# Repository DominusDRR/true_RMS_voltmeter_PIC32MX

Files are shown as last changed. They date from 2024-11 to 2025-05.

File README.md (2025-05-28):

# true_RMS_voltmeter_PIC32MX
AC voltmeter (true RMS) to measure 120VAC with a PIC32 microcontroller.

Project Description
This project features an alternating current (AC) voltmeter capable of measuring up to ±300V peak and a highly accurate frequency meter.

Key Features:
TRUE RMS Measurement: The device computes precise mathematical calculations on the analyzed signal to deliver an accurate true RMS value.
Frequency Meter: Accurately measures the frequency of the input AC signal, making it versatile for various applications.
Self-Powered Design: No external power source is required. The circuit is powered directly from the analyzed signal itself.

Texto alternativo (https://www.youtube.com/watch?v=dqBPHb_SDKo)

## [a. Project Concept.](ProjectConcept.md)
## [b. Signal conditioning circuit.](SignalConditioningCircuit.md)
## [c. Active filter design.](ActiveFilterDesign.md)
## [d. Assignment of microcontroller pins or terminals.](AssignmentMicrocontrollerPinsTerminals.md)
## [e. Simulation of the signal conditioning circuit.](SimulationSignalConditioningCircuit.md)
## [f. Signal conditioning testing with prototype hardware.](SignalConditioning.md)
## [g. PCB Layout.](PCBLayout.md)
## [h. RMS value calculation analysis.](RMSCalueCalculationAnalysis.md)  
## [i. Creating microcontroller code.](CreatingMicrocontrollerCode.md) 
## [j. Process of acquiring analog signal samples with the ADC.](ADC.md)
## [k. Task that controls the acoustic signal (buzzer).](Buzzer.md)
## [l. Task that manages the 7‐segment display.](Display.md)
## [m. Task that performs the RMS calculation.](RMS.md)
## [n. Task that manages the push button.](PushButton.md)

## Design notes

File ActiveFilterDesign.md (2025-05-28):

I have designed the second order filter with MCHP's FilterLab software, for a frequency of 1000 Hz.

Filter response

Filter response 2

I'm going to use 9.3k and 13k resistors respectively for R11 and R12, I don't think it will affect much for the designed frequency.

The idea of the filter is to eliminate any high frequency noise coming from the mains.

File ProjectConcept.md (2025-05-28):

I have a project in mind, which can be said to be more of a hobby than a professional one.

I need to measure the RMS voltage of the power grid, which must be 127VAC, however, that value varies on some occasions, so it is necessary to constantly visualize it.

A practical and effective solution would be to buy a voltmeter (digital or analogue) and that would be the whole challenge.

<p align="center">
  
</p>

However, since this is something I want to do for fun, I decided to build the voltmeter with elements I have, such as some microcontroller samples I acquired back in the day, but have never put them to practical use.

The first idea that occurred to me was to use a chip that is already a digital voltmeter. 

Digital voltmeter on a chip

This solution, I also think, would not be a big challenge. Obviously the PCB design and the placement of the elements would be something fun, but I prefer to write some code as well.

So I have decided to give it an additional plus. Apart from simply measuring and displaying the RMS voltage, I am going to add two more functionalities:

1. Using a push button, the hardware will stop displaying the voltage, and instead indicate the network frequency.

2. If the voltage is lower than a minimum value or higher than a maximum value, an acoustic signal will be activated to report said problem in the network.

Below I show a rather rough and incomplete block diagram of the hardware:

Block diagram

The first condition, which I chose, is that the maximum peak value of the AC voltage signal that the voltmeter could measure would be 300V (212.13 Vrms), this value is due to the fact that the microcontroller's ADC works with a maximum DC value of 3.0V, and in this way the calculations of the components could be in closed values (without many decimals).

So, when the voltage signal is 300V, at the ADC input it should be 3.0V, while when it is -300V, the voltage at the ADC input should be 0V.

This poses a system of 2 equations with two unknowns variables:

system of 2 equations with two unknown variables

When solving the equations, we have that the AC voltage signal must be given a gain (or rather, attenuated) and an offset added to it.

The gain (less than one, is 1/200) and the offset is 1.5V.

To attenuate the signal, as well as add the offset, I decided to use an operational amplifier in offset subtracter mode:

operational amplifier in offset subtracter mode

Where R1 and R2 would be 200k, Rf and Rx 1k and Vref 1.5V.

As I mentioned initially, I have several sample elements requested and left over from other projects, the operational amplifier I have is the MCP6L01, and I proceeded to perform a simulation with MPLAB Mindi to determine if this first part of the circuit works.

simulation with MPLAB Mindi

Something I remember right now is that the microcontroller works with 3.3V, but the ADC wants to work with a reference voltage of 3.0V, the reason is that using the same supply voltage is not exact, that is, it is close to 3.3V, but it usually varies slightly depending on various circumstances.

While having a fixed voltage reference, I think the ADC error would be smaller with respect to the LDO voltage.

Finally, the microcontroller I have is the PIC32MX170F256B.



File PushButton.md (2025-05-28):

The task that manages the pulsed pulses performs two actions, switching between the two operating modes, voltmeter and frequency meter; and eliminates the mechanical bounce.

The task has 3 states, the initial one, the one that eliminates the bounce and the last one that waits for the button to return to 1, if the user keeps it pressed.

<pre><code>typedef enum
{
    /* Application's state machine's initial state. */
    APPPULSADOR_ESTADO_INICIAL=0,
    APPPULSADOR_ESTADO_ELIMINAR_REBOTE,
    /* TODO: Define states used by the application state machine. */
    APPPULSADOR_ESTADO_ESPERAR_PULSADOR_REGRESE_A_1,
} APPPULSADOR_STATES;
</code></pre>

The data structure, apart from the state variable, has a flag that is used to determine the operating mode (voltmeter or frequency meter) and another 32-bit variable to be used to generate asynchronous delays.

<pre><code>typedef struct
{
    /* The application's current state */
    APPPULSADOR_STATES state;
    /* TODO: Define any additional data used by the application. */
    bool medirFrecuencia;
    int retardo;
} APPPULSADOR_DATA;
</code></pre>

In the initial state, the task is obviously initialized with the first state, and by default, the operation mode is voltmeter, that is, the medirFrecuencia flag is false.

<pre><code>void APPPULSADOR_Initialize ( void )
{
    /* Place the App state machine in its initial state. */
    apppulsadorData.state = APPPULSADOR_ESTADO_INICIAL;
    /* TODO: Initialize your application's state machine and other
     * parameters.
     */
    apppulsadorData.medirFrecuencia = false; // voltmeter mode
}</code></pre>

In the first state of the task, it waits for the button to be pressed and for the task that controls the buzzer to be at rest or in a higher state.

If so, medirFrecuencia switches state, that is, if it is true, it changes to false and vice versa, next the cambiarProceso function is called, which will change the operating states of the device, then the instantaneous value of the central timer is captured and the next state of the task is passed on.

<pre><code>case APPPULSADOR_ESTADO_INICIAL:
{
    if (false == PULSANTE_Get() && appbuzzerData.state >= APPBUZZER_ESTADO_REPOSO) // I wait for the button to be pressed
    {
        apppulsadorData.medirFrecuencia = !apppulsadorData.medirFrecuencia; //change the state of the boolean variable
        cambiarProceso();
        apppulsadorData.retardo = CORETIMER_CounterGet();
        apppulsadorData.state = APPPULSADOR_ESTADO_ELIMINAR_REBOTE;
     }
     break;
}</code></pre>

The cambiarProceso function restarts the tasks that perform ADC sampling and RMS calculation.

<pre><code>void cambiarProceso(void)
{
    APPSAMPLING_Initialize();   // Restart the sampling task
    APPRMS_Initialize();        // I restart the task that calculates the RMS value
}
</code></pre>

The debounce state waits for 200ms with an asynchronous delay before continuing.

The 200ms value is empirical, and it works very well for me.

After that delay, it is verified that the user has released the button to return to the initial state, otherwise, to the state where it waits for the user to stop pressing the button.

<pre><code> case APPPULSADOR_ESTADO_ELIMINAR_REBOTE:
{
   if ((CORETIMER_CounterGet() - apppulsadorData.retardo) > _200ms) 
   {
      if (false == PULSANTE_Get()) // the user continues to press the button
      {
         apppulsadorData.state = APPPULSADOR_ESTADO_ESPERAR_PULSADOR_REGRESE_A_1;
      }
      else
      {
         apppulsadorData.state = APPPULSADOR_ESTADO_INICIAL; // returns to wait for another keystroke
      }
    }
    break;
 }</code></pre>

In the state that waits for the user to release the button, that is, it is set to true.

Once the user releases the button, the state that eliminates the mechanical bounce is returned to.

<pre><code>
case APPPULSADOR_ESTADO_ESPERAR_PULSADOR_REGRESE_A_1:
{
    if (PULSANTE_Get()) // wait until the pulse returns to logic 1
    {
       apppulsadorData.retardo = CORETIMER_CounterGet();
       apppulsadorData.state = APPPULSADOR_ESTADO_ELIMINAR_REBOTE;
    }
    break;
}
/* The default state should never be executed. */
default: break; /* TODO: Handle error in application's state machine. */</code></pre>

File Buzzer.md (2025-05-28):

I have decided to use the buzzer to make a tune or music when the device is powered.

I have worked with the output comparator module before, doing exactly what I have described, and it works with a 16 or 32 bit timer to perform the comparison:

<p align="center">

</p>

In the MCC graphic area, I made a new group called buzzer:

<p align="center">

</p>

Inside which I have placed the OCMP1 module, which corresponds to the OC1 output:

<p align="center">

</p>

The features of the buzzer are as follows:

<p align="center">

</p>

There are several examples on the Internet of how to generate music with a PWM signal

The frequency of musical notes is in the approximate range from 200 Hz to 3000 Hz.

Therefore, to modify the PWM frequency, it is necessary to modify the PRy register of the associated timer:

<p align="center">

</p>

So, the value to compare is not important, but as a clock source, I select timer 3, so as not to interfere with the one that will be used with the square signal capture module synchronized with the sine wave:

<p align="center">

</p>

And I create a task with the name appBuzzer that will be dedicated to generating the initial music and warning tones:

<p align="center">

</p>

I have a project with a PIC32MZ microcontroller, with these definitions for each musical note, where each of them has the necessary frequency as a comment. For example, the musical note c_ corresponds to 261Hz, and the value to load in the PRy is 191570 to generate that frequency.

Obviously, for this microcontroller, which works at another frequency, I must recalculate those values.

<pre><code>#define mute 0
#define c_      191570 //       261 Hz underscore _ was used because there were conflicts with aws definitions or with freertos
#define d_      170067 //       294
#define e_      151974 //       329
#define f       143265 //       349
#define g       127876 //       391
#define gS      120481 //       415
#define a       113635 //       440
#define aS      112359 //       445
#define b       107295 //       466
#define cH      95601  //       523
#define cSH     90252  //       554
#define dH      85178  //       587
#define dSH     80385  //       622
#define eH      75872  //       659
#define fH      71632  //       698
#define fSH     67567  //       740
#define gH      63775  //       784
#define gSH     60240  //       830
#define aH      56817  //       880
                
#define cHH     23888   //      2093
#define AB      26823   //      1864
#define F6      35816   //      1396
#define d7      21285   //      2349
#define DE      20087   //      2489
#define f7      17901   //      2793
#define FG      16890   //      2960
#define GA      15050   //      3322
#define ABx     13407   //      3729
#define CD      22551   //      2217
#define E7      18960   //      2637
#define g7      15943   //      3136</code></pre>

According to the above definitions, the minimum frequency is 261 Hz and the maximum is 3136 Hz, this would imply a maximum period of the PWM signal of 3.831 ms and a minimum of 318.88 microseconds respectively.

Therefore, the PWM period should be greater than those 3.8 ms, for example the period could be 7 ms.

Playing with the parameters of timer 3, with a scaling of 8, that is, with 6 Mhz, and with PR3 equal to 42000, you would get 7 ms.

(42000/6MHz = 7 ms)

<p align="center">

</p>

Now, if we want a period of 318.88 us, PR3 = f* T = 6MHz * 318.88 us = 1913.26, which is a value that PR3 can have.

The equation to calculate the period of the PWM signal is:

<p align="center">

</p>

Where TPB is the clock frequency period of the peripheral bus, i.e. 1/48MHz.

TMR Prescaler Value is the pre-scaling value which is 8, i.e. TPB * TMR Prescaler Value = 1/6MHz.

With this I made a table in Excel to get the PR2 values for each audio frequency:

<p align="center">

</p>

And I paste it into the header file of the appbuzzer task: (obviously without decimals)

<p align="center">

</p>

A song is defined as a series of musical notes, and each note has a duration.

So I create a data structure as follows:

<pre><code>typedef struct
{
    unsigned int FrecuenciaNota; //frequency of the musical note
    unsigned int Tiempo;         //Time that a musical note lasts
}NotasMusicales;</code></pre>

Where NoteFrequency is the value of the timer's PR, and Time is the duration of the musical note, so I create an array with 12 musical notes like this:

<pre><code>NotasMusicales      Musica[0x0C];</code></pre>

I create this in the C file of the buzzer task.

<p align="center">

</p>

In the initial state of the task, what I do is initialize the 'music' array with the PR3 and delay values to generate the initial music.

<p align="center">

</p>

Remember that 1 ms is given by:

<pre><code>#define _1ms 0x5DC0</code></pre>

Also, in the initial state of the task (which I renamed) I disable everything related to the PWM configuration, otherwise it is possible that the buzzer makes sounds before the task starts to execute, and I start timer 3:

<p align="center">

</p>

I need a pointer to obtain each value of the array called Music, which will be part of the task data structure:

<p align="center">

</p>

And I initialize it in the C code of the task:

<p align="center">

</p>

Also, I need a variable to generate asynchronous (non-blocking) delays, and I write it in the data structure:

<p align="center">

</p>

To change the value of PR3, I create a function like this:

<pre><code>void actualizarFrecuenciaPWM(unsigned int frecuencia)
{
    TMR3_PeriodSet(frecuencia); //is similar to, PR3 = frecuencia (frequency);
    OCMP1_CompareSecondaryValueSet(frecuencia >> 1); // pulse width at 50%
}</code></pre>

Where I also try to make the PWM duty ratio % when writing to the OC1RS register, half the value of PR3.

At task initialization, I capture a value from the Core Timer, and generate the first note with the PWM using the actualizarFrecuenciaPWM function.

<p align="center">

</p>

In the initial state, I wait for the duration of each note using an asynchronous delay like this:

<p align="center">

</p>

When the delay has finished, the following is done:

A new core timer value is captured for the next delay.

I increment the pointer of the array called Music by 1.

If the pointer is still within the size of the music array, I check if the next note is mute, if so, I turn off the PWM to generate a silence.

If it is not mute, I update the value of PR3 with the value of the next note.

If the pointer is larger than the size of the array, the melody has finished, I turn off the PWM and jump to a state called sleep, where the task will wait until it wants to generate an acoustic signal.

That acoustic signal will be generated in a new state, but that will be later, for now I just want to create this part of the code.

Download the new code to the hardware and this is the result

<p align="center">

</p>

You can see that there is an unwanted tone before the melody starts.

I was assuming that some code is executed before initializing the task where I disable the PWM, I tried several things, for example setting the value to compare to 1 so that the initial pulse width is small, so that it does not generate that noise, like this:

<p align="center">

</p>

I also tried with a value equal to zero, but the result was the same.

I looked for where the PWM is initialized or activated, thinking that the generated code activated it ahead of time, but that is not the case. Where the PWM is activated is where I wrote OCMP1_Enable.

<p align="center">

</p>

So I came up with the idea of writing a note of silence, in the initial code, this implies that the Musica array is now 13 elements:

<p align="center">

</p>

By doing this, the melody sounded as it should.

"Test 2":https://www.youtube.com/watch?v=JiKf7lXYXPU

This task also activates an acoustic signal to inform if there is an overvoltage or an undervoltage, the levels for these levels are as follows:

<pre><code>#define maximoVoltaje       127.00
#define minimoVoltaje       110.00 
#define maximaFrecuencia    60.50
#define minimaFrecuencia    59.50</code></pre>

For an over-voltage, I want to make three audio pulses of 100 ms duration. Between each pulse there will be 200 ms, and before generating the three pulses again, I expect about 700 ms, something similar to this image which is not to scale.

<p align="center">

</p>

For an undervoltage, I think it will be a 100ms pulse, and between the next one, it will be about 700ms.

<p align="center">

</p>

I have created three more states, one that waits for the high tone, another that waits for the low tone and the third that waits for 700 ms to repeat the process again:

<pre><code>typedef enum
{
    /* Application's state machine's initial state. */
    APPBUZZER_ESTADO_INICIAL=0,
    APPBUZZER_ESTADO_REPOSO,
    /* TODO: Define states used by the application state machine. */
    APPBUZZER_ESTADO_PULSO_EN_ALTO,
    APPBUZZER_ESTADO_PULSO_EN_BAJO,
    APPBUZZER_ESTADO_PULSO_EN_SILENCIO
} APPBUZZER_STATES;</code></pre>

The task must be forced to change to the APPBUZZER_STATE_PULSE_ON_HIGH state, previously, the buzzer must be activated and the instantaneous value of the Core Timer must be captured to generate a 100ms delay.

This state would be like this:

<pre><code> case APPBUZZER_ESTADO_PULSO_EN_ALTO:
{
  if ((CORETIMER_CounterGet() - appbuzzerData.retardo) > _100ms)
  {
    OCMP1_Disable();
    appbuzzerData.retardo = CORETIMER_CounterGet();
    appbuzzerData.state = APPBUZZER_ESTADO_PULSO_EN_BAJO;
  }
  break;
}</code></pre>

Once the 100ms have elapsed, the buzzer is deactivated, an instantaneous value is captured again from the central timer for the next delay and the task status is changed to APPBUZZER_PULSE_STATE_IN_LOW.

The task data structure must have 3 additional data, an unsigned integer variable to capture the instantaneous value of the central timer, a variable where the number of desired audio pulses to be generated is written, and another that counts them,

<pre><code>typedef struct
{
    /* The application's current state */
    APPBUZZER_STATES state;
    /* TODO: Define any additional data used by the application. */
    unsigned char PunteroMusica;
    unsigned int retardo;
    unsigned char numeroPulsos; // number of pulses.
    unsigned char contadorPulsos; //pulse counter
} APPBUZZER_DATA;</code></pre>

The APPBUZZER_STATE_PULSE_IN_LOW state will be as follows, where 200ms is expected:

<pre><code>case APPBUZZER_ESTADO_PULSO_EN_BAJO:
{
     if ((CORETIMER_CounterGet() - appbuzzerData.retardo) > _200ms)
     {
         appbuzzerData.contadorPulsos--;
         if (appbuzzerData.contadorPulsos)
         {
             OCMP1_Enable();
             appbuzzerData.state = APPBUZZER_ESTADO_PULSO_EN_ALTO;
         }
         else
         {
             appbuzzerData.state = APPBUZZER_ESTADO_PULSO_EN_SILENCIO;
         }
         appbuzzerData.retardo = CORETIMER_CounterGet();
    }
    break;
</code></pre>

When 200 ms have passed, the variable pulse_counter is decremented. If it is still greater than zero (if (appbuzzerData. pulse_counter)), the buzzer is activated again and the task changes back to the APPBUZZER_PULSE_STATE_ON_HIGH state.

If it is zero (else), the task changes back to the APPBUZZER_PULSE_STATE_ON_SILENCE state.

This case does not end without first capturing the value that the Core Timer has at that moment.

In the APPBUZZER_PULSE_STATE_ON_SILENCE state, 500 ms are expected, which added to the previous 200, would give 700 ms.

<pre><code>case APPBUZZER_ESTADO_PULSO_EN_SILENCIO:
 {
     if ((CORETIMER_CounterGet() - appbuzzerData.retardo) > _500ms)
     {
           appbuzzerData.contadorPulsos = appbuzzerData.numeroPulsos;
           appbuzzerData.retardo = CORETIMER_CounterGet();
           OCMP1_Enable();
           appbuzzerData.state = APPBUZZER_ESTADO_PULSO_EN_ALTO;
     }
     break;
}</code></pre>

After the delay, the value of the variable pulse_counter is restored using pulse_number, the value of the Core Timer is captured again, the buzzer is activated and the state APPBUZZER_PULSE_STATE_ON_HIGH is returned to.

The function that changes the buzzer task's sleep time would be as follows:

<pre><code>void analizarNivelVoltaje(float voltajeRMS)
{
    if (appbuzzerData.state > APPBUZZER_ESTADO_INICIAL)
    {
        float valorMaximo;
        float valorMinimo;
        if (apppulsadorData.medirFrecuencia)
        {
            valorMaximo = maximaFrecuencia;
            valorMinimo = minimaFrecuencia;
        }
        else
        {
            valorMaximo = maximoVoltaje;
            valorMinimo = minimoVoltaje;
        }
        if (voltajeRMS > valorMaximo)
        {
            if (0x03 == appbuzzerData.numeroPulsos) // Overvoltage alarm is now present
            {
                return;
            }
            appbuzzerData.numeroPulsos = 0x03;
        }
        else if (voltajeRMS < valorMinimo)
        {
            if (0x01 == appbuzzerData.numeroPulsos) // Undervoltage alarm is now present
            {
                return;
            }
            appbuzzerData.numeroPulsos = 0x01;
        }
        else
        {
            appbuzzerData.numeroPulsos = 0x00;
            OCMP1_Disable();//apago el PWM
            appbuzzerData.state = APPBUZZER_ESTADO_REPOSO;
            return;
        }
        appbuzzerData.contadorPulsos = appbuzzerData.numeroPulsos;
        appbuzzerData.retardo = CORETIMER_CounterGet();
        actualizarFrecuenciaPWM(cHH);
        OCMP1_Enable();
        appbuzzerData.state = APPBUZZER_ESTADO_PULSO_EN_ALTO;
    }
}</code></pre>

This function should be called when the RMS value is calculated, and I have put it when the value on the displays is going to be modified:

<p align="center">

</p>

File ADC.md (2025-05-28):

The first basic conceptual idea is that the square signal that would be generated synchronized with the 60Hz network would be useful to start and stop the acquisition of data or samples from the ADC.

The start and stop would be by the rising or positive edge of said signal, as follows:

<p align="center">

</p>

The problem is that I don't know how many machine cycles it takes to calculate the RMS value (it could be measured), as you can see in the image above, once the data acquisition is finished, the CPU would concentrate on performing that calculation.

I don't think it would take a long time, but nevertheless, it would have to wait for the next cycle of the sinusoidal signal to perform a new data acquisition, I don't think it would affect the accuracy of the calculation, but I don't like the idea of wasting time doing that process.

The second option is to always be acquiring the data from the ADC.

This would imply using two buffers or arrays to store the information.

In the first cycle, it would save in the first array, then the task that calculates the RMS would perform its calculations with that array, but in that same cycle, the ADC information would be saved in the second array.

Then at the end of the second cycle, the RMS would be calculated with the second array, and the information would be stored in the first one, something like this image:

<p align="center">

</p>

So far, the idea that information is always being acquired from the sinusoidal signal seems to work, however, it is possible that the RMS calculation operations are atomic instructions, that is, they cannot be divided into more subfunctions, and executing them takes some time, so that, for example, if you are waiting for the data acquisition time, that time is longer, because some part of the RMS calculation is not finished.

The acquisition time is 1 us, the conversion time is approximately 14 us, and between each sample, you must wait 100 us:

<p align="center">

</p>

I was thinking about using polled mode, meaning I wait for a flag to finish, to know if the ADC conversion is ready. But as I mentioned, the CPU could be running an RMS calculation process, and until it finishes and checks that ADC flag again, the time will be longer, and possibly generate some precision error.

Also, I use asynchronous delays, which are not precise, and are used for tasks that are not so critical, for example, in the displays, each one shows information at a rate of 1000 us (1ms), but if for some moment it were 1015 us, for example, the user will not notice that.

Regarding the operation of the microcontroller's ADC.

The ADC has a 16-word buffer that I thought would be useful for acquiring 16 samples automatically.

<p align="center">

</p>

Now, the signal you want to sample with the ADC is approximately 60 Hz or a period of 16.667 ms.

The sampling must be much less than that time, for example if it were 100 times smaller, it would be 166.667 us, so you could choose a sampling rate of 100 us or 10 ksps.

Here you have to consider the acquisition time and the conversion time.

<p align="center">

</p>

According to the ADC converter section manual, the signal acquisition time is given by the ADCS bits of the ADCON3 register

<p align="center">

</p>

The minimum time must be greater than 83.33 ns.

<p align="center">

</p>

And in my case TpB is 1/48MHz.

<p align="center">

</p>

Looking for a correct value for the ADCS bits, I can say that 1 us acquisition time can be achieved:

<p align="center">

</p>

According to the manual, the conversion time is 12 times TAD, plus 1 or 2 additional TADs, therefore the conversion time would be approximately 14 us

<p align="center">

</p>

That is, the sampling would be at a rate of 15 us or 66.67 ksps.

This would allow for more samples, i.e. a more precise calculation, or perhaps use a delay to wait for the 100 us.

So I am forced to use interrupts, both, for the completion of the ADC conversion and for the generation of 100 us.

In that way, I think the latency produced by the RMS calculation process would be improved.

For the ADC converter interrupt, I take the MHCP example called adc_interrupt_pic32mx470_curiosity

And the example is as follows:

<pre><code>void ADC_ResultHandler(uintptr_t context)
{
    /* Read the ADC result */
    adc_count = ADC_ResultGet(ADC_RESULT_BUFFER_0);
    result_ready = true;
}

int main ( void )
{
    /* Initialize all modules */
    SYS_Initialize ( NULL );
    ADC_CallbackRegister(ADC_ResultHandler, (uintptr_t)NULL);
 
    printf("\n\r---------------------------------------------------------");
    printf("\n\r                    ADC Demo                 ");
    printf("\n\r---------------------------------------------------------\n\r");
 
    /* Start ADC conversion */
    ADC_ConversionStart();

    while (1)
    {
        /* Maintain state machines of all polled MPLAB Harmony modules. */
        SYS_Tasks ( );
 
        /* Auto sampling mode is used, so no code is needed to start sampling */
 
        /* Wait till ADC conversion result is available */
        if(result_ready == true)
        {
            result_ready = false;
            input_voltage = (float)adc_count * ADC_VREF / ADC_MAX_COUNT;
            printf("ADC Count = 0x%03x, ADC Input Voltage = %d.%02d V \r", adc_count, (int)input_voltage, (int)((input_voltage - (int)input_voltage)*100.0));
 
            /* Start ADC conversion */
            ADC_ConversionStart();
        }
    }
 
    /* Execution should not come here during normal operation */
 
    return ( EXIT_FAILURE );
}</code></pre>

It can be assigned or registered with the ADC_CallbackRegister function, which is the function that will handle the interruption at the end of the ADC conversion.

This function is called ADC_ResultHandler, where it obtains the value of the conversion and saves it in the variable adc_count

The configuration of this peripheral, with the graphic area of the MCC is as shown:

<p align="center">

</p>

Regarding the interruption by a timer, the example that I am going to take as a reference is called tmr_timer_mode_pic32mx_12_sk

<pre><code>/* This function is called after period matches in Timer 3 (32-bit timer) */
void TIMER2_InterruptSvcRoutine(uint32_t status, uintptr_t context)
{
    /* Toggle LED */
    LED1_Toggle();
}
// *****************************************************************************
// *****************************************************************************
// Section: Main Entry Point
// *****************************************************************************
// *****************************************************************************
 
int main ( void )
{
    /* Initialize all modules */
    SYS_Initialize ( NULL );
    
    TMR2_CallbackRegister(TIMER2_InterruptSvcRoutine, (uintptr_t) NULL);
    TMR2_Start();
 
    while ( true )
    {
        /* Maintain state machines of all polled MPLAB Harmony modules. */
        SYS_Tasks ( );
    }
 
    /* Execution should not come here during normal operation */
 
    return ( EXIT_FAILURE );
}</code></pre>

The function that registers the one that is called when the interruption occurs is called TMR2_CallbackRegister and is on line 18.

And the TIMER2_InterruptSvcRoutine function only toggles the logical state of an LED.

This example uses timer 2 in 32-bit mode, which means that timer 3 works together to achieve that bit width.

<p align="center">

</p>

In the TMR2 module, it is configured to 32 bits, and it is indicated that the enabling of the interrupt must be done in the secondary or slave timer, in this case it is the TMR3, and its configuration is:

<p align="center">

</p>

I was initially thinking of using the capture module to measure the frequency of the AC signal, it also has an external interruption:

<p align="center">

</p>

In theory, only one of the two options could be used, but using the System module, you could enable that interrupt:

<p align="center">

</p>

Then I create a new group, called adquisicion:

Within this new group, I add the ADC module, which has the following configurations.

- The interrupt is enabled
- The clock source is from the 48 MHz peripheral bus.
- The clock divider is 23, to get 1000 ns (1 us) of acquisition time, as I mentioned at the beginning.
- The voltage reference is VREF+ and AVSS (GND) where VERF + will be 3.0V
- Channel 0 of the ADC will be connected to the analog input AN1.
- The result of the conversion will be a 32-bit integer number

<p align="center">

</p>

I also add timer 4, in 16-bit mode to generate 100 us:

<p align="center">

</p>

Using the Core module, I create a new task called appSampling, which will be in charge of initializing the enabling of the external interrupt, and this in turn will enable the ADC and TMR4 interrupts at the same time:
<p align="center">
<img src="https://pbs.twimg.com/media/F6zUyWHXUAAxsYy?format=png&name=medium!
</p>

I have a structure where I have an array that will be the buffer that stores the data acquired by the ADC and an 8-bit variable that is a pointer to that array:

<pre><code>typedef struct
{
    unsigned short  bufferADC[256]; // stores each sample acquired by the ADC
    unsigned char   muestra;        // points to each of the ADC buffer elements
}EstructuraADC;</code></pre>

While the task data structure is like this:

<pre><code>typedef struct
{
    /* The application's current state */
    APPSAMPLING_STATES state;
    /* TODO: Define any additional data used by the application. */
    EstructuraADC   estructuraADC[0x02]; //There are two that alternate, one acquires and with the other the RMS is calculated.
    unsigned char   punteroABuffer; // Points to punteroABuffer, i.e. it is 0 or 1
    bool    periodoCompleto; //Reports that one period of the AC signal has been completed
    uint32_t captura[0x02]; //Captures the value to measure the period of the AC signal.
    unsigned char indiceCaptura; // Points to captura, i.e. it is 0 or 1
} APPSAMPLING_DATA;
</code></pre>

The start of the task is as shown in the following code snippet:

<pre><code>void APPSAMPLING_Initialize ( void )
{
    /* Place the App state machine in its initial state. */
    appsamplingData.state = APPSAMPLING_ESTADO_INICIAL;
    /* TODO: Initialize your application's state machine and other
     * parameters.
     */
    appsamplingData.punteroABuffer  = 0x01; //I point to the second buffer, so that with INT2, it starts at 0 (First buffer)
    appsamplingData.estructuraADC[0x00].muestra = 0x00; // muestra (sample) buffer 0 initialized
    appsamplingData.estructuraADC[0x01].muestra = 0x00; // muestra (sample) buffer 1 initialized
    
    appsamplingData.periodoCompleto = false;
}</code></pre>

The task is basically just two states:

<pre><code>void APPSAMPLING_Tasks ( void )
{
    /* Check the application's current state. */
    switch ( appsamplingData.state )
    {
        /* Application's initial state. */
        case APPSAMPLING_ESTADO_INICIAL:
        {
            if (apppulsadorData.medirFrecuencia) // apppulsadorData.medirFrecuencia is variable of the task that manages the push button
            {
                /** I disable everything related to the calculation of the RMS value **/
                EVIC_ExternalInterruptDisable(EXTERNAL_INT_2);  //I stop the interrupt by external interruption
                EVIC_SourceStatusClear(INT_SOURCE_EXTERNAL_2);  //clear flag due to external interruption
                TMR4_Stop();                                    //I stop timer 4
                TMR4_InterruptDisable();                        //I disable timer interrupt 4
                EVIC_SourceStatusClear(INT_SOURCE_TIMER_4);     //clear tmr4 interrupt flag
                ADC_Disable();                                  //I disable the ADC module
                EVIC_SourceStatusClear(INT_SOURCE_ADC);         //clear the flag due to ADC interruption
                /*************************************************/
                ICAP1_Enable();//I enable the capture module
                TMR2_Start(); //I start tmr2
                ICAP1_CallbackRegister(ManejarInterrupcionModuloCaptura, (uintptr_t)NULL);//The ManejarInterrupcionModuloCaptura function will be called by the capture module interrupt
                appsamplingData.captura[0x00] = 0x0000;//
                appsamplingData.captura[0x01] = 0x0000;//
                appsamplingData.indiceCaptura = 0x00;//
            }
            else
            {
                /** I disable everything related to the calculation of the signal period **/
                ICAP1_Disable(); //I disable the capture module
                TMR2_Stop();// Stop timer 2
                EVIC_SourceStatusClear(INT_SOURCE_INPUT_CAPTURE_1); // clear capture module flag.
                /*************************************************/
                TMR4_Stop();
                TMR4_CallbackRegister(ManejarInterrupcionTMR4, (uintptr_t) NULL);//register function invoked by TMR4 interrupt
                ADC_CallbackRegister(ManejarInterrupcionADC, (uintptr_t)NULL); // register function invoked by ADC interrupt
                EVIC_ExternalInterruptCallbackRegister(EXTERNAL_INT_2, &ManejarInterrupcionExterna, (uintptr_t)NULL); //Register the function that is called by the external interrupt
                EVIC_ExternalInterruptEnable(EXTERNAL_INT_2); // I enable external interrupt 2
                
                TMR4_InterruptEnable();//I enable TMR4 interrupt
                ADC_Enable(); //I enable ADC
            }
            appsamplingData.state = APPSAMPLING_ESTADO_REPOSO; //Task goes to sleep, change with push button
            break;
        }

        case APPSAMPLING_ESTADO_REPOSO: break;
        /* TODO: implement your application state machine.*/
        /* The default state should never be executed. */
        default: break; /* TODO: Handle error in application's state machine. */
    }
}</code></pre>

As you can see, when the voltmeter option is selected, the external interruption is enabled, by positive edge.

This interruption occurs at the beginning of each period of the sinusoidal signal, and the function that is invoked in this interruption is ManejarInterrupcionExterna.

<pre><code>void ManejarInterrupcionExterna (EXTERNAL_INT_PIN pin, uintptr_t context)
{
    /** Cambio de buffer **/
    appsamplingData.punteroABuffer++;   // void ManejarInterrupcionExterna (EXTERNAL_INT_PIN pin, uintptr_t context)
{
    appsamplingData.punteroABuffer++;   // points to the next buffer, one is for acquisition, and the other is for rms calculation.
    if (appsamplingData.punteroABuffer > 0x01)
    {
        appsamplingData.punteroABuffer = 0x00; //Return to buffer 0
    }
    else
    {
        appsamplingData.periodoCompleto = true;//Indicates that a period has been completed, obviously the first time the buffer will have all its bytes at zero.
    }
    appsamplingData.estructuraADC[appsamplingData.punteroABuffer].muestra = 0x00; //clear buffer pointer (sample)
    TMR4_Stop();                        // Stop TMR4:
    TMR4 = 0x0000;                      // Clear/reset the count
    ADC_ConversionStart();              // Start the conversion
    TMR4_Start();                       // start timer 4
}
}</code></pre>

Once timer 4 starts running, it will generate an interrupt every 100 us, and the function that is called at each interrupt is ManejarInterrupcionTMR4.

<pre><code>void ManejarInterrupcionTMR4(uint32_t status, uintptr_t context)
{
    ADC_ConversionStart();  //start the ADC conversion again, at 100 us
}</code></pre>

When the ADC conversion completes, it also generates an interrupt, which in turn invokes the function:

<pre><code>void ManejarInterrupcionADC(uintptr_t context)
{
    appsamplingData.estructuraADC[appsamplingData.punteroABuffer].bufferADC[appsamplingData.estructuraADC[appsamplingData.punteroABuffer].muestra] = ADC_ResultGet(ADC_RESULT_BUFFER_0);
    
    AD1CON1bits.ADON = 0;  // turn off ADC
    IFS0bits.AD1IF = 0;    // clear the interrupt flag
    /***********************/
    appsamplingData.estructuraADC[appsamplingData.punteroABuffer].muestra++;
    //IFS0CLR = _IFS0_AD1IF_MASK; //MCHP's alleged solution
}</code></pre>

*Here I have to explain that there was a bug with the ADC, despite being configured to generate a single conversion, the end of conversion interrupt was generated twice.
Searching the forum, I found someone who suggested turning off the ADC and turning it back on, it is a cumbersome solution, but it works.
MCHP, in an open ticket, claims that writing IFS0CLR = _IFS0_AD1IF_MASK should clear the interrupt flag, since that was the reason that two interrupts were produced, but I have not tested it.*

In the frequency meter mode, however, the module that works with timer 2 captures the value of said timer at the beginning of each period of the sinusoidal signal.

With these two captures, a value is obtained that is the result of the difference of these two values, which corresponds to the measured time.

And the value in Hertz of said value is obtained, to send it to the 4-digit display.

<pre><code>void ManejarInterrupcionModuloCaptura(uintptr_t context)
{
    appsamplingData.captura[appsamplingData.indiceCaptura++] = ICAP1_CaptureBufferRead();
    if (appsamplingData.indiceCaptura > 0x01)
    {
        float diferencia = (float)(appsamplingData.captura[0x01]) -  (float)(appsamplingData.captura[0x00]);
        if (diferencia > 0.00)
        {
            rmsDisplay(750000.000/diferencia);
        }
        appsamplingData.indiceCaptura = 0x00;
    }
}</code></pre>

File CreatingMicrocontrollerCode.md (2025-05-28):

I'm going to do the project with XC32, with MPLAB Harmony 3 and with MCC.

I'm leaving the steps in images if someone, at some point, wants to create a project with the mentioned tools.

First, in MPLAB X I start a new project with H3 with MCC:

Create a project

Then I select another window that opens, where I must select the path where the H3 repository was downloaded.



Next, I indicate where I want to create my project:



Finally, I select the microcontroller I want to use.



Then the content manager wizard opens, where I select the option for H3.





Finally the MCC looks like this:



With the System module, you can calibrate the configuration bits, also known as fuses.



The first configuration word is called DEVCFG3 and has three parts.

USERID allows us to add an identification number that could be the firmware version or any other information.

A feature of this MCU family is that the outputs or inputs of various peripherals can be ‘placed’ on different terminals of the MCU. This is an advantage over other microcontrollers because very often several peripherals share the same terminals. For example, if the RS232 asynchronous serial communication module is used, the SPI module could no longer be used and vice versa.

With this microcontroller family, this problem is easily solved by assigning the inputs and outputs of the other peripheral to other terminals.

The peripherals that do not have this advantage are the I2C communication module and the ADC converter, whose terminals are fixed.

Setting PMDL1WAY to ON allows us to block the Peripheral Module once, which allows us to disable a peripheral module once, until the MCU's external terminals are correctly assigned. After all the peripherals have been correctly configured, there is no way to modify the PPS again until the MCU is restarted.

Setting IOL1WAY to ON allows us to block the RPnR registers once for the correct assignment of the terminals to the peripheral.

DEVCFG3

DEVCFG2 and DEVCFG1 are related to the oscillator, so I prefer to use the graphical part of the oscillator to configure it.

DEVCFG2 & DEVCFG1

The microcontroller CPU can work at 50MHz, but I have an 8MHz crystal, so the next frequency would be 48MHz.

System Clock

If you go back to the settings for DEVCFG2 and DEVCFG1, you will see that some bits have changed.



**Note that the FNOSC bit of DEVCFG1 is in FRCPLL, this stands for Fast RC PPL, which is a high speed internal RC oscillator, and I don't want to use that oscillator, I want to use the crystal.**

And what I want to use is XT plus frequency multiplier (PLL)



FNOSC

The IESO bit controls the dual-speed start-up. When the system is powered on, the crystal or oscillator needs some time to stabilize properly. Enabling the dual-speed mode with the IESO bit allows the CPU to use the internal oscillator first and then switch to the main oscillator. In our case, I will not use this functionality, but I must use the timer related to the Power On Reset (POR) until the main oscillator stabilizes.

FPBDIV allows you to define the frequency at which the peripherals will work and is a multiple of the CPU oscillation frequency. We will leave it at a value equal to 1, that is, without division.

FCKSM has 3 sub-options. The FSCM or Fail-Safe Clock Monitor monitors that the main oscillator works correctly. If there is a fault, it can switch to an internal oscillator so that the CPU continues working. I think I will leave the FSCM and oscillator switching disabled. Or maybe I should go for the internal oscillator switching option.

I want to use the watchdog, so I set its overflow to 1024ms, and the window options for that timer, I won't use (set to OFF)

WDT Configuration

Regarding DEVCFG0, it has five options, the first is called JTAGEN and allows debugging through JTAG, which is an IEEE standard for an access port to test or debug a device. I will use an ICD3 or a SNAP; so this option will be OFF.

The second option allows us to configure which ICSP channel will be used and in this case it is number 2.

Regarding the write protections in the program memory and bootloader, since it is a homemade project and I do not plan to create a remote update, I do not plan to activate those boxes, only the read protection through an external programmer.

The Background debugger, I leave it OFF, it is not something unimportant either, since it is a homemade project, and it is automatically set to ON, if I use the programmer/debugger to debug with the hardware.

DEVCFG0

The next step is to configure the microcontroller pins or terminals.



I configure each of the terminals according to the desired design.



In device resources search and add the Core module:



Whenever I add this module, it always asks me if I want to use FreeRTOS, but for this simple example, I don't think it's necessary.



With the Core module, I check the box to generate application files, this allows you to create state machine tasks or processes, and I like that way of writing code.



I create tasks for each peripheral that I want to control or a particular process that I want to be independent.

For the moment I create two, the first one will be to control the display, and the second one will be the one that performs the process of calculating the rms value.



Later, I will continue to add other tasks.

I also add the Core Timer to generate asynchronous delays, for any delay in the code. So I go back to the Root group and add that module to have the libraries for that peripheral.



To generate the code, I must press the button called 'Generate'



The code may have something similar.



_**So far, the fundamental steps to create the project code have been explained. You can close the MCC and if you need to change or add something, you must invoke the MCC again.**_

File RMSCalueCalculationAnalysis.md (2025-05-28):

To calculate the RMS I must meet the following condition of several samples acquired by the ADC according to the following equation:



The maximum value measured by the ADC would correspond to 300V, while the minimum is -300V (Obviously this signal must be conditioned to the maximum and minimum values of the ADC)

Before applying the equation above, I think I should change the values obtained from the ADC to voltage levels.

The ADC has 4 options for the conversion result



**Each of the values must be multiplied by a slope or gain m and added to a shift or constant c, to arrive at the minimum and maximum voltage values.**

 V(t) = (ADC value(t))* m + c

For the first option it would be:

1023*m + c = 300
0*m + c = -300

From here m = 200/341 and c = -300.

For the second option it would be:

511*m + c = 300
-512*m + c = -300, where m = 200/341 and c = 0.293

For the third option it would be:

0.999*m + c = 300
0*m + c = -300 , where m = 600.6006 and c =-300

And the last one would be:

0.499*m + c = 300
-0.5*m + c = -300, where m = 109.111 and c = 245.

**With these results I think that the first option seems to be the best.** (32 bits Integer format)

That is to say, each value obtained from the ADC must be multiplied by m and added to c. The result must be squared and each of these values must be added.

The total sum must be divided by the number of samples obtained in the time period, and this new result must be taken as the square root.

Now, it seems to me that this constant m could be taken out of the summation, and the constant c would be another separate summation, that is to say, I think that before multiplying each value by m and adding c, the summation could be performed without altering the acquired values yet, and then, with the final result, I would multiply by a gain and add it.

In this way, I could relieve the calculation load on the microcontroller's CPU.

So the equation to calculate the RMS value would be like this:



I started doing some tests with the code and the MPLAB X simulator.

The first thing I did was imagine that I had 100 samples of a perfect sinusoidal signal, with RMS of 120V.

The conditioning circuit changes the 300V input signal to 3.0V which would be 1023 on the ADC, with -300, the signal would be 0.0V and the ADC would also be 0.

If my signal is 120VAC, it means that the peak value would be 169.7056V.

The conditioning circuit with the operational amplifier, gives a gain of 1/200 to the signal and adds a constant of 1.5.

Therefore.

169.7056/200 + 1.5 = 2.3482V

-168.7056/200 + 1.5 = 0.65147V

If the ADC, for 3.0V, is 1023, performing a simple rule of 3.

3.0V---- is equivalent to ---- > 1023

2.3482--- is equivalent to 800.84.81 (801 being an unsigned integer)

0.65147-- is equivalent to 222.1519 (222 for an unsigned number)

I create a vector or array (called arreglo) to store these samples, and I do it in the data structure of the appRMS task:



Now, with the help of Excel, I generate the 100 samples of the signal, the formula used is:

**=341*((169.7056/200)*SIN(2*PI()*A3/100)+1.5)**



I copy and paste all those values for the array in file c, of the task.



The code in C would be like this:



I ran the simulation, and the code that performs the RMS value calculation seems to work.



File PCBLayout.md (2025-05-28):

The PCB is trying to adapt to these plastic cases

<p align="center">
  
</p>

<p align="center">
  
</p>

<p align="center">
  
</p>

<p align="center">

</p>

This is the schematic of the system power supply

<p align="center">

</p>

Regarding the power supply, I placed a rectifier diode before the 5V regulator (D4) to avoid reverse bias when using an external power supply, which I will use when I want to debug the microcontroller firmware:

Additionally, the 1mA load (15k) needed by the 15V power supply was replaced by an LED diode with its limiting resistor (LED1 and R5).

The schematic of the microcontroller and the 4-digit display

<p align="center">

</p>

The schematic of the conditioning circuit. (Note that I changed the 1k and 200k resistors of the subtracting amplifier, for 10k and 200M resistors to give a greater input impedance to the signal that you want to analyze its RMS value.)

<p align="center">

</p>

This is what PCBs look like after arriving from the factory:
<p align="center">

</p>

The first thing I did was place the elements that make up the voltage source
<p align="center">

</p>

And the voltage produced is close to 15V DC.

<p align="center">

</p>

This is how it ended up with the microcontroller and everything needed to control the 7-segment display.
<p align="center">

</p>

In the initialization of the task that manages the display, I set the default number to 4567, and this is how it is displayed.
<p align="center">

</p>

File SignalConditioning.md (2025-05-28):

I'm going to do some real signal conditioning tests with the op-amp. I have a few on PCBs for use in a protoboard.

OP fo test

I have performed the tests with the op-amp to determine if the conditioning works as the simulation predicted.

I should point out that for this test I used common resistors (for the project I will use 1% tolerance surface resistors), and I have not yet used the voltage reference circuit, which is something I did not have and is a purchase that is on the way. So I used a resistor array to get approximately 1.5V.

Prototype Hardware

When I looked at the conditioned signal, I got this, which for a moment I thought was some kind of distortion of the sinusoidal signal. I had the idea that the op amp, or the circuit was properly conditioning the signal, but distorting the waveform.

Conditioned signal

So I decided to connect the oscilloscope directly to the mains to see what the voltage signal was like, and the distortion came from there and it was not the fault of the circuit with the operational (I put the scope test lead x10)

electric mains

So far, we can say that the signal conditioning works, obviously it is not precise because of the resistors used, and the voltage reference I got is 1.4V.

I used one of the 4 opamps available for the comparator, to generate a square wave synchronized with the zero crossing of the sine wave and this is the result:

Zero crossing detection

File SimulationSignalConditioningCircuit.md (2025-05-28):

I had some doubts if the voltage follower to produce 1.5 would work correctly and with the comparator to create the square wave signal synchronized with the zero crossing.

First I checked the 1.5 V reference and this is what I got (Output of Op X2)

Simulation of 1.5V reference

You can see that there is noise in the 1.5V signal, a reflection of the AC signal of approximately 70 uV peak to peak, maybe I should use an RC filter to eliminate it, with the consequence of increasing the impedance of the reference signal, or use another follower after the filter to avoid this possible problem.

Then I checked the Op X3, it behaves appropriately as a comparator and this is what I got:

Simulation 2

So it seems that noise on the 1.5V reference is not a problem.

**Note that I have not yet installed the high-frequency filter of the differential offset amplifier, whose output is the one I should use to compare to 1.5V.**

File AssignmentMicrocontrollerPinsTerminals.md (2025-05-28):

The microcontroller pin assignment will be as follows:

Pin distribution

I'll explain this in more detail below.

Terminal 1 is the reset, so it will need to be connected to the RC network recommended by the manufacturer.

Terminal 2 will be the external 3.0V reference for the ADC.

Terminal 3 will be the input to the ADC.

ADC Module

The entire port B will be the data bus for the 7-segment display.

Display

Because it is a 4 digit display:

Display 3D

I need to scan each digit, for which terminals RB8, RB9, RB12 and RB13 will control each digit.

Terminals RA2 and RA3 will be for the internal crystal oscillator. _**I had the idea of using the internal RC oscillator, but since it is not precise, I don't know how big the error in the measurements will be.**_

I am forgetting the acoustic signal, for which I must generate a square wave, precisely with the remaining terminal RB15, it can be the output of the comparison module 1 to generate a PWM signal.

PWM Buzzer

And that's all for now, I'll start designing the PCB when I have a bit more time. And when I finish another board of my work, I plan to send them together to manufacture both at the same time.

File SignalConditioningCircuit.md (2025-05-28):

The conditioning circuit can be approximated by the following schematic:



Below I explain what each part should do.

1. Amplifier OA1. This forms the offset differential that was explained at the beginning of the project description.

2. Amplifier OA2. This is the 1.5V reference source. Note that to create this reference, I start from the 3.0V voltage reference circuit LM4040D30ILPR, and by means of a simple divider with resistors, I obtain the 1.5V.



I use this amplifier for impedance matching, since a voltage source or reference must have a low impedance with respect to the load, but the voltage divider with resistors R6 and R7 do not meet this condition, so a voltage follower meets the necessary characteristic.

3. OA3 amplifier. 

With this amplifier I want to create an active filter to eliminate any high frequency noise, generally high frequency noise could alter the microcontroller CPU causing a failure or a reset. It is not the final design and I have not yet calculated the values, the reference is the Butterworth filter (Or is it Chebyshev? I don't remember, I have to determine it when necessary)

4. OA4 amplifier.

I need to detect the zero crossing of the sinusoidal signal to start acquiring data and also measure its period (frequency).
By adding, the signal varies on a 1.5V axis, so using the reference of that value and the conditioned signal to generate a square wave that will reach the microcontroller and allow it to detect when a period of the signal begins and ends.

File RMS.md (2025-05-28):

This task has 4 states, one initial, two summations, one to calculate the square root and one of rest or laziness.

<pre><code>typedef enum
{
    /* Application's state machine's initial state. */
    APPRMS_ESTADO_INICIAL=0,
    APPRMS_ESTADO_SUMATORIO_1,
    /* TODO: Define states used by the application state machine. */
    APPRMS_ESTADO_SUMATORIO_2,
    APPRMS_ESTADO_EXTRAER_RAIZ_CUADRADA,         
    APPRMS_ESTADO_IDLE        
} APPRMS_STATES;</code></pre>

It is divided in this way to avoid a complete appropriation of the CPU when performing calculations.

<pre><code>typedef struct
{
    /* The application's current state */
    APPRMS_STATES state; //state machine
    /* TODO: Define any additional data used by the application. */
    float sumatorio1; //Result of summation 1
    float sumatorio2; //Result of summation 2
    unsigned char indice; //Used to perform a non-preemptive for loop
    unsigned char puntero; // Allows me to select between the two buffers that store ADC information
    //unsigned int retardo; //variable for asynchronous delays
} APPRMS_DATA;</code></pre>

In the initial state, if the working mode is frequency meter, the task goes to sleep, otherwise the RMS calculation is performed.

<pre><code>void APPRMS_Initialize ( void )
{
    if (apppulsadorData.medirFrecuencia)
    {
       apprmsData.state = APPRMS_ESTADO_IDLE;
    }
    else
    {
        /* Place the App state machine in its initial state. */
        apprmsData.state = APPRMS_ESTADO_INICIAL;
        /* TODO: Initialize your application's state machine and other
        * parameters.
        */
    }
}</code></pre>

In the first state, we wait for a period of the AC signal to have been sampled, if so, we initialize the variables, select the buffer that will calculate the RMS value and jump to the second state that performs the calculation of the first summation.

<pre><code>case APPRMS_ESTADO_INICIAL:
{
     if (appsamplingData.periodoCompleto)
     {
          apprmsData.indice = 0x00;
          apprmsData.sumatorio1 = 0.0;
          apprmsData.sumatorio2 = 0.0;
          apprmsData.puntero = (appsamplingData.punteroABuffer == 0x01)? 0 : 1;
          appsamplingData.periodoCompleto = false;
          apprmsData.state = APPRMS_ESTADO_SUMATORIO_1;
      }
     break;
}</code></pre>

The first summation is to add each item squared in the buffer.
This summation is done once per state, which means that it does not take up the CPU.

Once this summation is finished, it is multiplied by m squared, (m is the slope indicated in literal h. RMS value calculation analysis)

<pre><code>case APPRMS_ESTADO_SUMATORIO_1: // sumatorio(x^2)
{
   if (apprmsData.indice < appsamplingData.estructuraADC[apprmsData.puntero].muestra)
   {
     apprmsData.sumatorio1 += powf((float)(appsamplingData.estructuraADC[apprmsData.puntero].bufferADC[apprmsData.indice]),2);
     apprmsData.indice++;
   }
   else
   {
       apprmsData.indice = 0x00;
       apprmsData.sumatorio1 = 0.34399*apprmsData.sumatorio1; // m^2* sumatorio1
       apprmsData.state = APPRMS_ESTADO_SUMATORIO_2;
   }
   break;
}</code></pre>

The second summation (also not CPU-intensive) performs the sum of each of the items in the buffer being analyzed.

At the end, this sum is multiplied by 2mc, see literal h (RMS value calculation analysis)

Both summations (1 and 2) are added plus the number of samples times the constant c squared.

And finally, that total sum is divided by the number of samples.

<pre><code>case APPRMS_ESTADO_SUMATORIO_2:
{
       if (apprmsData.indice < appsamplingData.estructuraADC[apprmsData.puntero].muestra)
       {
           apprmsData.sumatorio2 += (float)(appsamplingData.estructuraADC[apprmsData.puntero].bufferADC[apprmsData.indice]);
           apprmsData.indice++;
       }
       else
       {
           apprmsData.sumatorio2 = -351.9062*apprmsData.sumatorio2; //2mc* sumatorio2(x)
          apprmsData.sumatorio1 = apprmsData.sumatorio1 + apprmsData.sumatorio2 + 90000*(float)           (appsamplingData.estructuraADC[apprmsData.puntero].muestra)/* - 90000*/;  // (N-1)*C^2 
          apprmsData.sumatorio1 = apprmsData.sumatorio1/((float)appsamplingData.estructuraADC[apprmsData.puntero].muestra);
          apprmsData.state = APPRMS_ESTADO_EXTRAER_RAIZ_CUADRADA;
       }
       break;
}
</code></pre>

The fourth state is simply to obtain the square root of the calculation performed in the previous case and send it to the display task.

<pre><code> case APPRMS_ESTADO_EXTRAER_RAIZ_CUADRADA:
   {
      rmsDisplay(sqrtf(apprmsData.sumatorio1)); //square root and send it to display
      apprmsData.state = APPRMS_ESTADO_INICIAL;
      break;
   }
</code></pre>

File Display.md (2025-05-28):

First I create an unsigned char array of length 4, for each digit of the 7-segment display.

This array needs a variable as an index or pointer, and since it is only 4 digits, it can also be an unsigned char.

I also need a signed int variable that I will use to create asynchronous delays in this task.

<pre><code>typedef struct
{
    /* The application's current state */
    APPDISPLAY_STATES state;
    /* TODO: Define any additional data used by the application. */
    unsigned char arregloDisplay[0x04]; //array of length 4
    unsigned char punteroDisplay; //index for aarray
    unsigned int retardo; // Variable used to capture the value of the Core Timer and create non-blocking delays
} APPDISPLAY_DATA;
</code></pre>

Being a common anode display, the values to be represented by each digit would be the following:

<p align="center">
 
</p>

I can make a function to return each value based on a variable in one statement, but I prefer to use an array in flash memory. This array will be in the c file of the assignment.

<pre><code>//                                          0     1    2    3    4    5   6    7    8   9     0.   1.   2.    3.   4.   5.   6.   7.   8.   9. 
const unsigned char digitoDisplay[0x14] = {0xC0,0xF9,0xA4,0xB0,0x99,0x92,0x82,0xF8,0x80,0x98,0x40,0x79,0x24,0x30,0x19,0x12,0x02,0x78,0x00,0x18};</code></pre>
*Note that from the tenth digit onwards, numbers from 0 to 9 are represented again but with a decimal point. This implies that if you want to represent a number with a decimal point, you must add 10. For example, if you want to represent 7, the corresponding symbol would be from position 17.*

Port B is not 8 bits, meaning that what is going to be written to it must be masked so as not to alter bit 8, bit 9, etc. of that port.

It would be something like this with an or at the byte level:

<pre><code>LATB = 0xFFFFFF00 | value obtained from the array</code></pre>

Or, I can use Harmony's abstraction to manipulate the port:

<pre><code>void GPIO_PortWrite(GPIO_PORT port, uint32_t mask, uint32_t value);</code></pre>

Where port is obviously the port, mask indicates which bits you want to alter and value is the value you want to write.

The mask must be 1 for the bits you want to be altered, and 0 otherwise.

In my case it would be like this:

<pre><code>GPIO_PortWrite(GPIO_PORT_B, 0x0000FF,  valor obtenido del arreglo);</code></pre>

When initializing the task, I set the display pointer and the value for each digit to zero:

<pre><code>void APPDISPLAY_Initialize ( void )
{
    /* Place the App state machine in its initial state. */
    appdisplayData.state = APPDISPLAY_STATE_INIT;
 
    /* TODO: Initialize your application's state machine and other
     * parameters.
     */
    appdisplayData.punteroDisplay = 0x00; //punteroDisplay points to the first display
    appdisplayData.arregloDisplay[0x00] = 0x00; //initial value at zero
    appdisplayData.arregloDisplay[0x01] = 0x00; //initial value at zero
    appdisplayData.arregloDisplay[0x02] = 0x00; //initial value at zero
    appdisplayData.arregloDisplay[0x03] = 0x00; //initial value at zero
}</code></pre>

Empirically from other projects I have determined that the activation frequency of each display can be 1 ms, obviously it would be necessary to test it with the hardware, but I leave it for now.

In the first state of the task that I renamed ESTADO_INICIAL, I capture the value of the Core Timer, to move on to the next state that I have called MOSTRANDO_DATOS.

<pre><code>void APPDISPLAY_Tasks ( void )
{
 
    /* Check the application's current state. */
    switch ( appdisplayData.state )
    {
        /* Application's initial state. */
        case APPDISPLAY_ESTADO_INICIAL: //initial state
        {
           
            appdisplayData.retardo = CORETIMER_CounterGet();
            appdisplayData.state = APPDISPLAY_ESTADO_MOSTRANDO_DATOS;
            break;
        }
 
        case APPDISPLAY_ESTADO_MOSTRANDO_DATOS://status displaying data on the display
        {
 
            break;
        }
 
        /* TODO: implement your application state machine.*/
        /* The default state should never be executed. */
        default: break;  /* TODO: Handle error in application's state machine. */
    }
}</code></pre>

In the second state of the task, you should wait 1 ms to change the information to each digit on the display:

<pre><code>case APPDISPLAY_ESTADO_MOSTRANDO_DATOS:
{
       if ((CORETIMER_CounterGet() - appdisplayData.retardo) > _1ms) 
       {
                
       }
       break;
}</code></pre>

The constant _1ms is calculated based on the clock cycles counted by the CORE TIMER.

This timer works at half the system frequency, i.e. 24 MHz, meaning that each cycle is 41.666 ns, so to get 1 ms, it would be 1ms/41.666ns = 24000 or 0x5DC0

<pre><code>#define _1ms 0x5DC0</code></pre>

To access the value you want to display, you must use the array containing the value using the display pointer variable, like this:

<pre><code>appdisplayData.arregloDisplay[appdisplayData.punteroDisplay]</code></pre>

But this value is not suitable to be displayed on the screen, so the array created in flash memory is used, that is:

<pre><code>digitoDisplay[appdisplayData.arregloDisplay[appdisplayData.punteroDisplay]]</code></pre>

To put this value in port B, using the function to write a number to port, using harmony 3 it would be as follows:

<pre><code>GPIO_PortWrite(GPIO_PORT_B, 0x0000FF, (uint32_t) digitoDisplay[appdisplayData.arregloDisplay[appdisplayData.punteroDisplay]]);</code></pre>

And the base of each PNP transistor that controls the display digit must also be activated, which is something I have not considered so far.

By default, in the MCC, pins RB8, RB9, RB12 and RB13 are configured to logic 1 (each display digit off), but I could set them to logic 1 at the start of the task:

<pre><code>void APPDISPLAY_Initialize ( void )
{
    /* Place the App state machine in its initial state. */
    appdisplayData.state = APPDISPLAY_ESTADO_INICIAL;
 
    /* TODO: Initialize your application's state machine and other
     * parameters.
     */
    /*** I turn off each of the digits on the display ***/
    DISPLAY1_Set();
    DISPLAY2_Set()
    DISPLAY3_Set();
    DISPLAY4_Set();
    /***********************************************/
    appdisplayData.punteroDisplay = 0x00; //punteroDisplay points to the first display
    appdisplayData.arregloDisplay[0x00] = 0x00; //initial value at zero
    appdisplayData.arregloDisplay[0x01] = 0x00; //initial value at zero
    appdisplayData.arregloDisplay[0x02] = 0x00; //initial value at zero
    appdisplayData.arregloDisplay[0x03] = 0x00; //initial value at zero
}</code></pre>

What I need is to use the same pointer of the display array to select terminals RB8, RB9, RB12 and RB13.

With the following function, I could activate each digit of the display.

<pre><code>GPIO_PortClear(GPIO_PORT_B,bit del puerto);</code></pre>

Then I again write a 4-byte array into flash memory to manipulate the 4 bits.

<pre><code>//                                             bit8   bit9  bi12    bit13
const unsigned short bitsDigitoDisplay[0x04] = {1<<8, 1<<9, 1<<12, 1<<13};</code></pre>

So it would be like this, but it is still incomplete:

<pre><code>case APPDISPLAY_ESTADO_MOSTRANDO_DATOS:
{
      if ((CORETIMER_CounterGet() - appdisplayData.retardo) > _1ms) 
      {
          GPIO_PortWrite(GPIO_PORT_B, 0x0000FF, (uint32_t) digitoDisplay[appdisplayData.arregloDisplay[appdisplayData.punteroDisplay]]);
          GPIO_PortClear(GPIO_PORT_B,bitsDigitoDisplay[appdisplayData.punteroDisplay]);
          appdisplayData.punteroDisplay++;
      }
      break;
}</code></pre>

I need to turn off the display before it is going to be activated:

<pre><code>GPIO_PortSet(GPIO_PORT_B,bitsDigitoDisplay[appdisplayData.punteroDisplay - 0x01]);</code></pre>

but that is not feasible if punteroDisplay is equal to zero, so it would be like this:

<pre><code>if (appdisplayData.punteroDisplay > 0x00)
 {
     GPIO_PortSet(GPIO_PORT_B,bitsDigitoDisplay[appdisplayData.punteroDisplay - 0x01]);
 }
 else // si appdisplayData.punteroDisplay  es cero, se debe apagar el 4to dígito
 {
      GPIO_PortSet(GPIO_PORT_B,bitsDigitoDisplay[0x03]);
 }</code></pre>

It is also necessary to verify that when incrementing the pointer, it should not exceed 3:

<pre><code>if (appdisplayData.punteroDisplay > 0x03)
{
   appdisplayData.punteroDisplay = 0x00;
}</code></pre>

After all this, the task must again capture a value from the CORE TIMER, to generate another delay.

So the second state of the task would be like this:

<pre><code>case APPDISPLAY_ESTADO_MOSTRANDO_DATOS:
{
    if ((CORETIMER_CounterGet() - appdisplayData.retardo) > _1ms) 
    {
        if (appdisplayData.punteroDisplay > 0x00)
        {
            GPIO_PortSet(GPIO_PORT_B,bitsDigitoDisplay[appdisplayData.punteroDisplay - 0x01]); //Turn off to previous digit
        }
        else //if appdisplayData.punteroDisplay is zero, the 4th digit should be turned off
        {
            GPIO_PortSet(GPIO_PORT_B,bitsDigitoDisplay[0x03]);
        }
        GPIO_PortWrite(GPIO_PORT_B, 0x0000FF, (uint32_t) digitoDisplay[appdisplayData.arregloDisplay[appdisplayData.punteroDisplay]]);
        GPIO_PortClear(GPIO_PORT_B,bitsDigitoDisplay[appdisplayData.punteroDisplay]);
        appdisplayData.punteroDisplay++;
        if (appdisplayData.punteroDisplay > 0x03)
        {
            appdisplayData.punteroDisplay = 0x00;
        }
        appdisplayData.retardo = CORETIMER_CounterGet(); // I capture another Core Timer value again for another delay
    }
    break;
}</code></pre>

This task would be working independently, any value that you want to show on the display must be done from another task or process by modifying the values of the appdisplayData.arregloDisplay array.

/////////////////////////////////////////////////////////////////////////

To display the RMS value (or the frequency value) on the display, a function called rmsDisplay was created.

The function first obtains its integer and decimal parts, since the parameter it needs is of the float type.

The function evaluates whether the value to be displayed is greater than 99, that is, from then on, if it is greater than 9 and less than or equal to 99, and from 0 to 9.

For the first case, the integer value is placed in the first 3 digits, the second being the one with the decimal point and the fourth, showing the decimal part.

For the second case, the integer part is shown in the first two digits, the third has the decimal point, and the third and fourth show the decimal part.

For the last case, only the first digit shows the integer part.

<pre><code>oid rmsDisplay(float valorRMS)
{
    analizarNivelVoltaje(valorRMS);
    int parteEntera = (int)floorf(valorRMS);
    float parteDecimal = (float)(valorRMS - parteEntera);
    if (parteEntera > 99)
    {
        appdisplayData.arregloDisplay[0x03] = (unsigned char)floorf(parteDecimal *10); 
        appdisplayData.arregloDisplay[0x02] = 10 + (unsigned char)(parteEntera%10); // sumo diez para activar el punto decimal
        appdisplayData.arregloDisplay[0x01] = (unsigned char)((parteEntera/10)%10); 
        appdisplayData.arregloDisplay[0x00] = (unsigned char)(parteEntera/100);
    }
    else if (parteEntera > 9)
    {
        int decimalDosDigitos = (int)floorf(parteDecimal *100); 
        
        appdisplayData.arregloDisplay[0x03] = (unsigned char)(decimalDosDigitos%10);
        appdisplayData.arregloDisplay[0x02] = (unsigned char)(decimalDosDigitos/10); 
        
        appdisplayData.arregloDisplay[0x01] = 10 +(unsigned char)(parteEntera%10); // sumo diez para activar el punto decimal
        appdisplayData.arregloDisplay[0x00] = (unsigned char)(parteEntera/10);
    }
    else
    {
        int decimalTresDigitos = (int)floorf(parteDecimal *1000); 
        
        appdisplayData.arregloDisplay[0x03] = (unsigned char)(decimalTresDigitos%10); 
        appdisplayData.arregloDisplay[0x02] = (unsigned char)((decimalTresDigitos/10)%10); 
        appdisplayData.arregloDisplay[0x01] = (unsigned char)(decimalTresDigitos/100); // obtengo centena
        
        appdisplayData.arregloDisplay[0x00] = (unsigned char)(parteEntera);
    }
}</code></pre>

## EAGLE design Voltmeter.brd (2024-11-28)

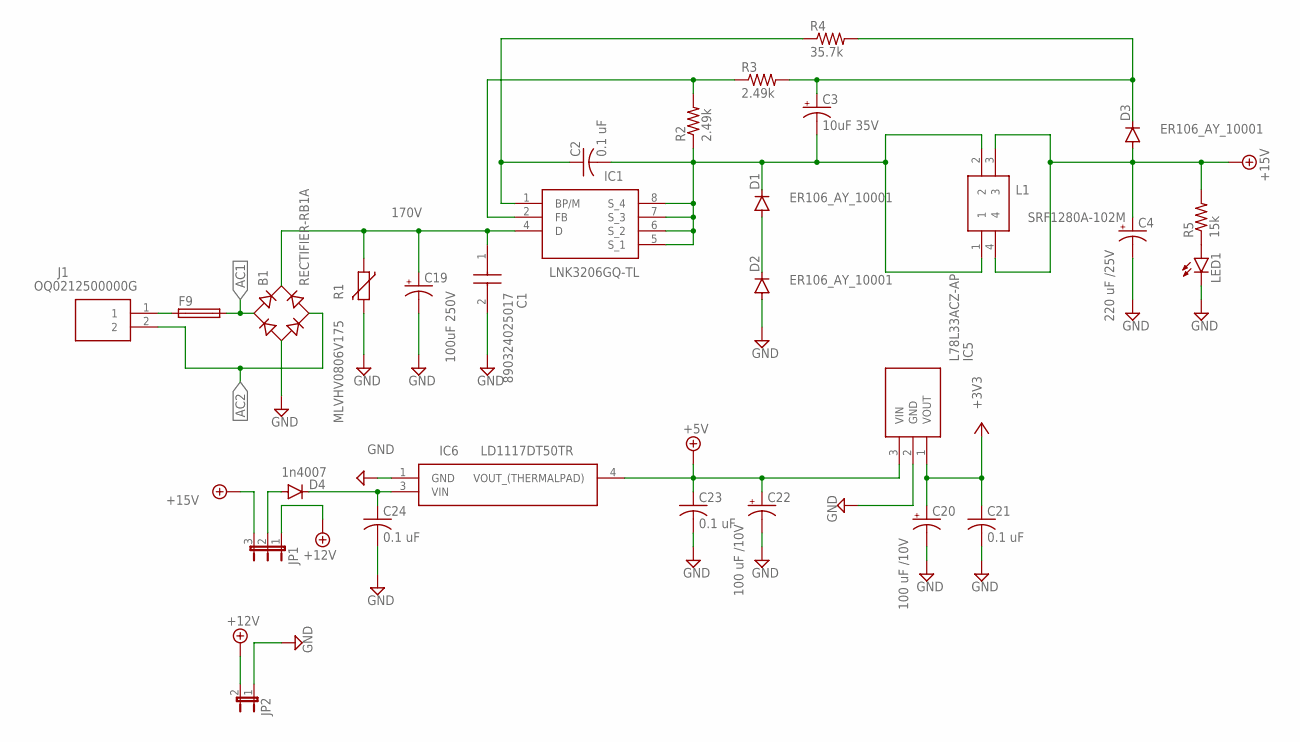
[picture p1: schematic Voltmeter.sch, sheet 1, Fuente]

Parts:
B1: RECTIFIER-RB1A; RB1A
C1: 890324025017
C2, C21, C23, C24: 0.1 uF; C0603K
C3: 10uF 35V; E2,5-6
C4: 220 uF /25V; E3,5-8
C19: 100uF 250V; E5-10,5
C20, C22: 100 uF /10V; E2-5
D1, D2, D3: ER106_AY_10001; DO41-7.6
D4: 1n4007; DO41-7.6
F9: LITTLEFUSE
IC1: LNK3206GQ-TL; TOP253GNTL
IC5: L78L33ACZ-AP; TS1107A1AP
IC6: LD1117DT50TR; TO228P972X240-3N
J1: OQ0212500000G
JP1: JP2E; JP2
JP2: JP1E; JP1
L1: SRF1280A-102M; SRF1280A102M
LED1: LEDSML0805; SML0805
R1: MLVHV0806V175; CT/CN1206
R2, R3: 2.49k; R0603
R4: 35.7k; R0805
R5: 15k; R0603

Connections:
170V: B1.+, C1.1, C19.+, IC1.4 (D), R1.1
+3V3: C20.+, C21.1, IC5.1 (VOUT); also elsewhere on the board
+5V: C22.+, C23.1, IC5.3 (VIN), IC6.4 (VOUT_(THERMALPAD)); also elsewhere on the board
+12V: JP1.1, JP2.2
+15V: C4.+, D3.A, JP1.3, L1.3, L1.4, R5.2
AC1: B1.AC1, F9.2; also elsewhere on the board
AC2: B1.AC2, J1.2; also elsewhere on the board
GND: B1.-, C1.2, C4.-, C19.-, C20.-, C21.2, C22.-, C23.2, C24.2, D2.A, IC5.2 (GND), IC6.1 (GND), JP2.1, LED1.C, R1.2; also elsewhere on the board
unnamed: C2.1, IC1.1 (BP/M), R4.1
unnamed: C2.2, C3.-, D1.C, IC1.5 (S_1), IC1.6 (S_2), IC1.7 (S_3), IC1.8 (S_4), L1.1, L1.2, R2.1
unnamed: IC1.2 (FB), R2.2, R3.1
unnamed: C3.+, D3.C, R3.2, R4.2
unnamed: D1.A, D2.C
unnamed: D4.A, JP1.2
unnamed: LED1.A, R5.1
unnamed: C24.1, D4.C, IC6.3 (VIN)
unnamed: F9.1, J1.1

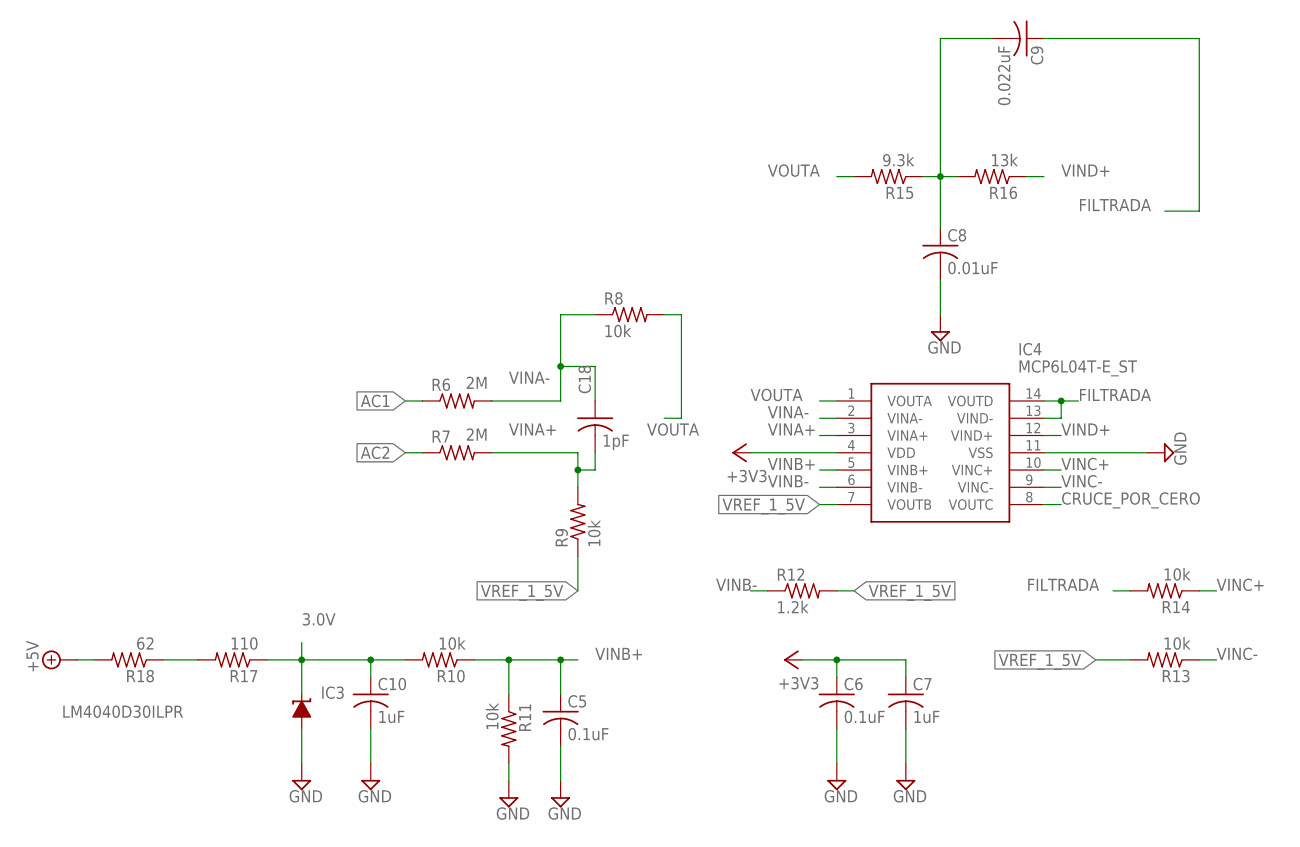
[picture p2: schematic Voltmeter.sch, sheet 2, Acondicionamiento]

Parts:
C5, C6: 0.1uF; C0603K
C7, C10: 1uF; C0603K
C8: 0.01uF; C0603K
C9: 0.022uF; C0603K
C18: 1pF; C0603K
IC3: LM4040D30ILPR; LP_O-PBCY-W3
IC4: MCP6L04T-E_ST; SOP65P640X120-14N
R6, R7: 2M; R0603
R8, R9, R10, R11, R13, R14: 10k; R0603
R12: 1.2k; R0603
R15: 9.3k; R0603
R16: 13k; R0603
R17: 110; R0603
R18: 62; R0603

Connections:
3.0V: C10.1, IC3.2 (C), R10.2, R17.1; also elsewhere on the board
+3V3: C6.1, C7.1, IC4.4 (VDD); also elsewhere on the board
+5V: R18.2; also elsewhere on the board
AC1: R6.1; also elsewhere on the board
AC2: R7.1; also elsewhere on the board
CRUCE_POR_CERO: IC4.8 (VOUTC); also elsewhere on the board
FILTRADA: C9.1, IC4.13 (VIND-), IC4.14 (VOUTD), R14.2; also elsewhere on the board
GND: C5.2, C6.2, C7.2, C8.2, C10.2, IC3.3 (A), IC4.11 (VSS), R11.2; also elsewhere on the board
unnamed: C8.1, C9.2, R15.1, R16.2
unnamed: R17.2, R18.1
VINA+: C18.2, IC4.3 (VINA+), R7.2, R9.2
VINA-: C18.1, IC4.2 (VINA-), R6.2, R8.1
VINB+: C5.1, IC4.5 (VINB+), R10.1, R11.1
VINB-: IC4.6 (VINB-), R12.1
VINC+: IC4.10 (VINC+), R14.1
VINC-: IC4.9 (VINC-), R13.1
VIND+: IC4.12 (VIND+), R16.1
VOUTA: IC4.1 (VOUTA), R8.2, R15.2
VREF_1_5V: IC4.7 (VOUTB), R9.1, R12.2, R13.2

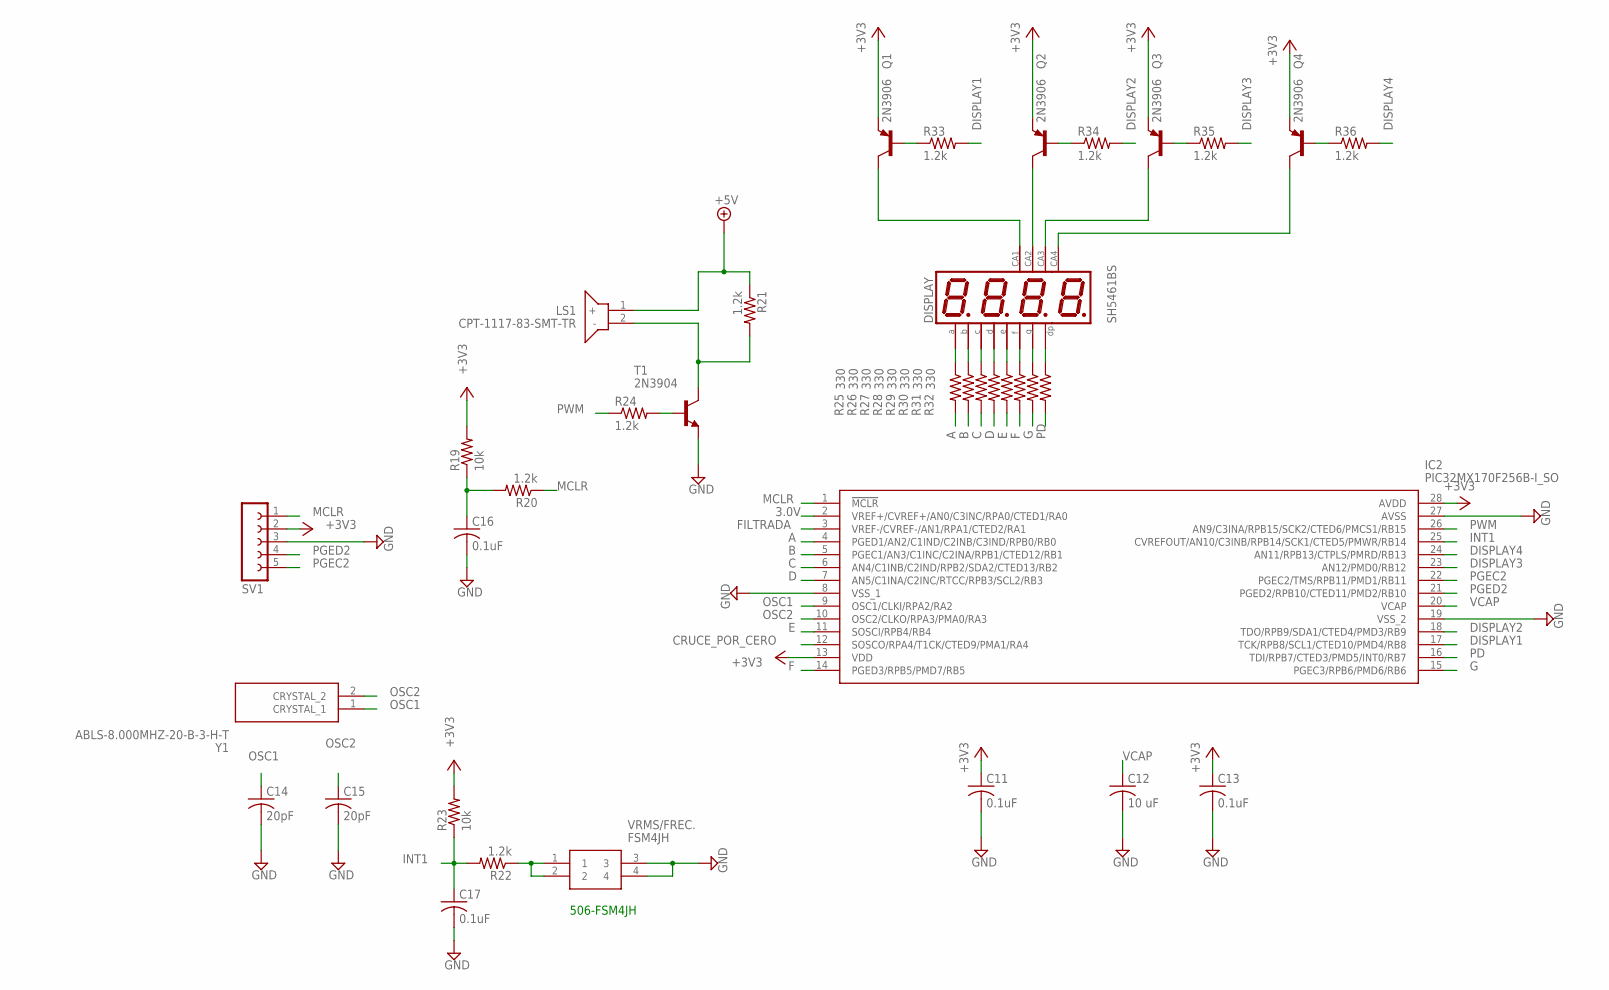
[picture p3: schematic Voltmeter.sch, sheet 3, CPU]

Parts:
C11, C13, C16, C17: 0.1uF; C0603K
C12: 10 uF; C1206
C14, C15: 20pF; C0603K
DISPLAY: SH5461BS; BX56_FR3
IC2: PIC32MX170F256B-I_SO; SOIC127P1030X265-28N
LS1: CPT-1117-83-SMT-TR; CPT111783SMTTR
Q1, Q2, Q3, Q4: 2N3906; TO92
R19, R23: 10k; R0603
R20, R21, R22, R24, R33, R34, R35, R36: 1.2k; R0603
R25, R26, R27, R28, R29, R30, R31, R32: 330; R0603
SV1: FE05-1
T1: 2N3904; TO92
VRMS/FREC.: FSM4JH
Y1: ABLS-8.000MHZ-20-B-3-H-T; ABLS8000MHZ20B3HT

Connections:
3.0V: IC2.2 (VREF+/CVREF+/AN0/C3INC/RPA0/CTED1/RA0); also elsewhere on the board
+3V3: C11.1, C13.1, IC2.13 (VDD), IC2.28 (AVDD), Q1.3 (E), Q2.3 (E), Q3.3 (E), Q4.3 (E), R19.2, R23.2, SV1.2; also elsewhere on the board
+5V: LS1.1 (+), R21.1; also elsewhere on the board
A: IC2.4 (PGED1/AN2/C1IND/C2INB/C3IND/RPB0/RB0), R25.2
B: IC2.5 (PGEC1/AN3/C1INC/C2INA/RPB1/CTED12/RB1), R26.2
C: IC2.6 (AN4/C1INB/C2IND/RPB2/SDA2/CTED13/RB2), R27.2
CRUCE_POR_CERO: IC2.12 (SOSCO/RPA4/T1CK/CTED9/PMA1/RA4); also elsewhere on the board
D: IC2.7 (AN5/C1INA/C2INC/RTCC/RPB3/SCL2/RB3), R28.2
DISPLAY1: IC2.17 (TCK/RPB8/SCL1/CTED10/PMD4/RB8), R33.2
DISPLAY2: IC2.18 (TDO/RPB9/SDA1/CTED4/PMD3/RB9), R34.2
DISPLAY3: IC2.23 (AN12/PMD0/RB12), R35.2
DISPLAY4: IC2.24 (AN11/RPB13/CTPLS/PMRD/RB13), R36.2
E: IC2.11 (SOSCI/RPB4/RB4), R29.2
F: IC2.14 (PGED3/RPB5/PMD7/RB5), R30.2
FILTRADA: IC2.3 (VREF-/CVREF-/AN1/RPA1/CTED2/RA1); also elsewhere on the board
G: IC2.15 (PGEC3/RPB6/PMD6/RB6), R31.2
GND: C11.2, C12.2, C13.2, C14.2, C15.2, C16.2, C17.2, IC2.8 (VSS_1), IC2.19 (VSS_2), IC2.27 (AVSS), SV1.3, T1.3 (E), VRMS/FREC..3, VRMS/FREC..4; also elsewhere on the board
INT1: C17.1, IC2.25 (CVREFOUT/AN10/C3INB/RPB14/SCK1/CTED5/PM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), R22.2, R23.1
MCLR: IC2.1 (!MCLR), R20.1, SV1.1
unnamed: C16.1, R19.1, R20.2
unnamed: LS1.2 (-), R21.2, T1.1 (C)
unnamed: R24.2, T1.2 (B)
unnamed: R22.1, VRMS/FREC..1, VRMS/FREC..2
unnamed: DISPLAY.11 (A), R25.1
unnamed: DISPLAY.12 (CA), Q1.1 (C)
unnamed: DISPLAY.7 (B), R26.1
unnamed: DISPLAY.4 (C), R27.1
unnamed: DISPLAY.2 (D), R28.1
unnamed: DISPLAY.1 (E), R29.1
unnamed: DISPLAY.10 (F), R30.1
unnamed: DISPLAY.5 (G), R31.1
unnamed: DISPLAY.3 (DP), R32.1
unnamed: Q1.2 (B), R33.1
unnamed: DISPLAY.9 (CA), Q2.1 (C)
unnamed: DISPLAY.8 (CA), Q3.1 (C)
unnamed: DISPLAY.6 (CA), Q4.1 (C)
unnamed: Q2.2 (B), R34.1
unnamed: Q3.2 (B), R35.1
unnamed: Q4.2 (B), R36.1
OSC1: C14.1, IC2.9 (OSC1/CLKI/RPA2/RA2), Y1.1 (CRYSTAL_1)
OSC2: C15.1, IC2.10 (OSC2/CLKO/RPA3/PMA0/RA3), Y1.2 (CRYSTAL_2)
PD: IC2.16 (TDI/RPB7/CTED3/PMD5/INT0/RB7), R32.2
PGEC2: IC2.22 (PGEC2/TMS/RPB11/PMD1/RB11), SV1.5
PGED2: IC2.21 (PGED2/RPB10/CTED11/PMD2/RB10), SV1.4
PWM: IC2.26 (AN9/C3INA/RPB15/SCK2/CTED6/PMCS1/RB15), R24.1
VCAP: C12.1, IC2.20 (VCAP)

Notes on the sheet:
506-FSM4JH

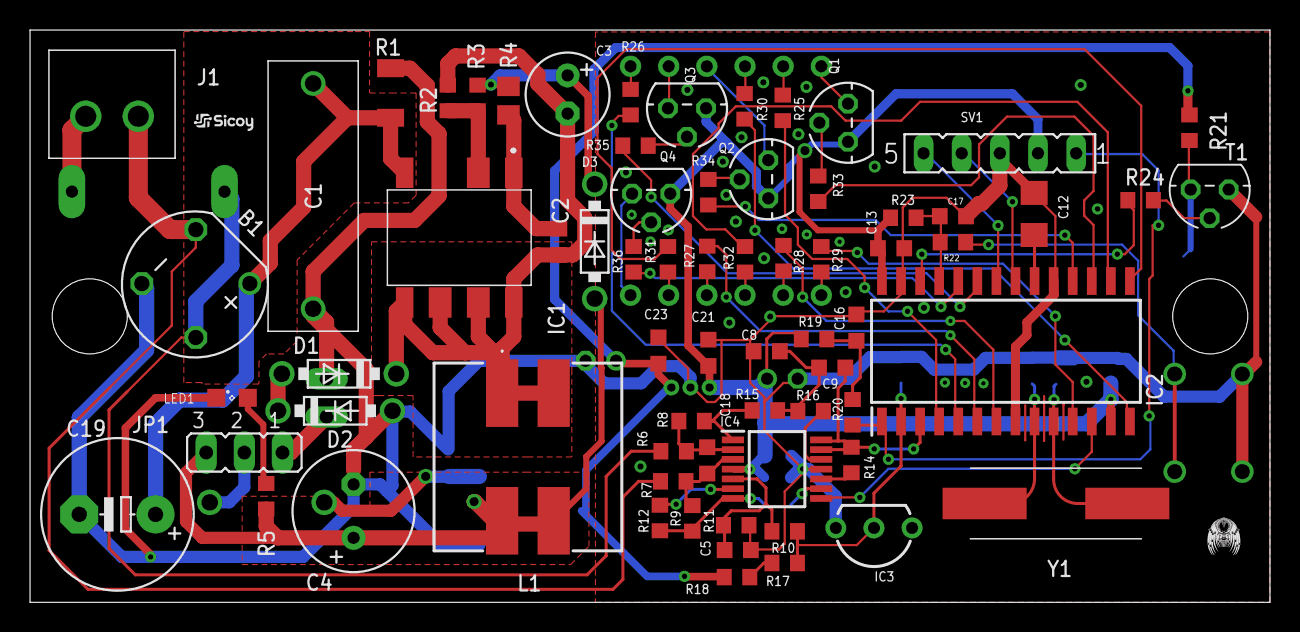
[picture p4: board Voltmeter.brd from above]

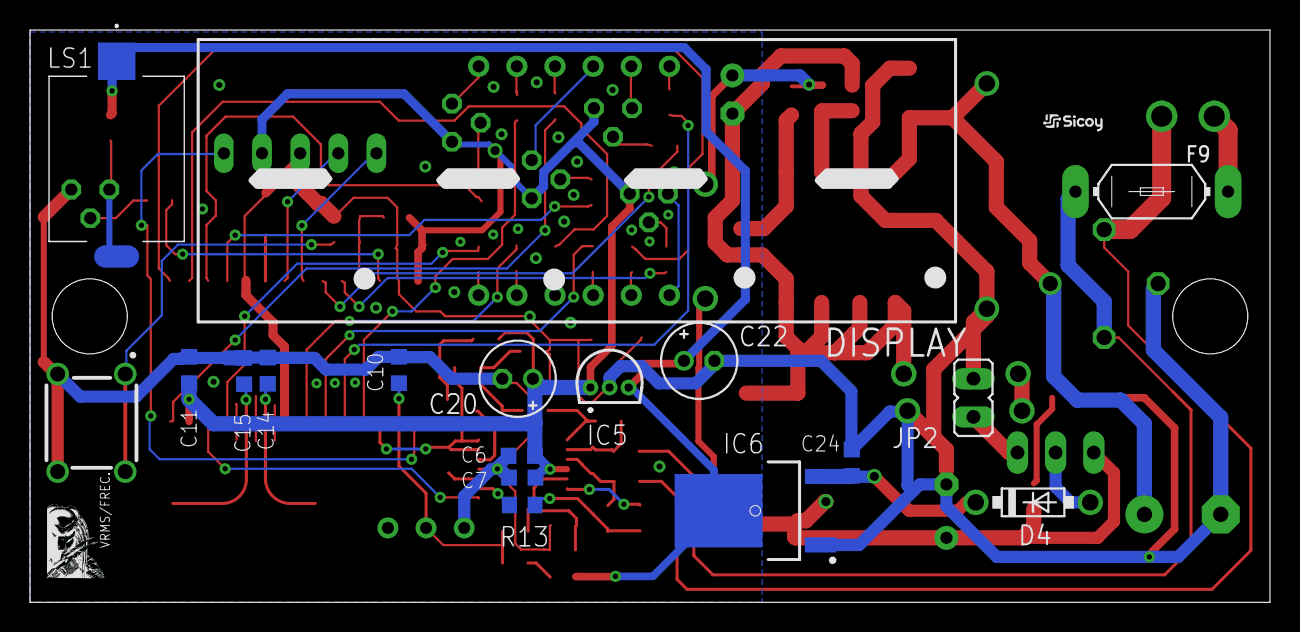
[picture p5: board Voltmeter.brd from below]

Board: 2 copper layers, 82.5 x 38.1 mm, 87 parts (18 on the bottom side), 71 nets.

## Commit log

2024-11-28 Voltmeter PCB created in EAGLE PCB
    [Voltmeter.brd, Voltmeter.sch]
2024-12-12 Hexadecimal file
    Hexadecimal file of the voltmeter project with the PIC32MX170F256B microcontroller
